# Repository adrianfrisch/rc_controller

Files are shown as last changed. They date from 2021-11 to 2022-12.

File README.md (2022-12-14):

# Universal DIY Remotecontroller

For my RC and robotics projects, I needed a better way to remote control my devices. 
So this is my attempt on building a handheld remote control, which I can use on any of 
my current and future projects.

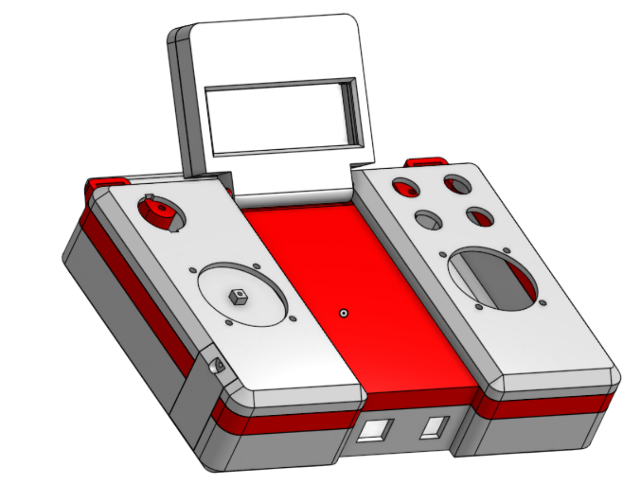
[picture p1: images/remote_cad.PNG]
CAD design screenshot

## Goals
The new controller should have two operation modes. Since I used the App "Bluetooth RC Controller" 
in the past for a project, It should have a bluetooth operation mode which operates similar and can be used 
instead of the mobile phone with app.
For other projects the transmission should be in the 2.4 GHz band to achieve a higher range.
The display should be readable also outdoors in the sun so I decided to go with a simple LCD 
module instead of a more fancy TFT.

## Features
- Bluetooth mode
- 2.4 GHz mode
- Push buttons for mode selection. After mode has been selected, can be used as switches to trigger actions
- After operation mode (BT / 2.4GHz) has been selected, a target device can be selected
- list of potential target devices will be configured in firmware
- two joystick knobs
- A display to show information
- power switch

## Benefits
- Just one remote necessary
- Reasonable price (I payed ~70€ for the parts)
- Very flexible
- Can display useful information or telemetry data on remote

## Specifications
This list contains all of the used components to put everything together
### Hardware / Bill of Materials
*Electronics*
- 1x Arduino Mega Microcontroller
- 1x HD44780 1602 LCD Module
- 1x NRF24L01 2.4GHz Transceiver
- 1x HC05 Bluetooth Transceiver
- 1x 220Ohms resistor
- 1x 10-100uF capacitor
- 1x 10kOhms linear potentiometer
- 2x 10kOhms resistor
- 1x Power Switch
- 4x Push Buttons
- 2x 4-Axis joystick potentiometer
- 1x 2s 7.4V  900mAh Lipo battery
*3D printed parts*
- 1x lower body 
- 1x upper body
- 1x left panel
- 1x right panel
- 1x handle
- 1x display case front
- 1x display case backplate
- 1x battery cover plate
- 2x display connector
*Screws, nuts etc.*
- 10x M2 Screws 6mm
- 12x 3x10mm screws
- 2x M4 Screws 12mm
- 4x M4 Washers
- 2x M4 Nuts
- hot glue
- CA glue
- heat shrink tube
## Test results
It is still work in progress. First successful data transmitted but lots of work remaining.
## Identified problems
It is still work in progress. First successful data transmitted but lots of work remaining.
## Future ideas
- The backplate of the LCD display mount needs to be glued at the moment. Add proper lid with screws.
- Calibration on power up as a "third mode selection" to allow recalib and eliminate need for 
  hardcoding in the firmware
- Save telemetry data to SD for latter analysis
- Build a corresponding universal receiver which can be used as a "plug in replacement" for a 
  standard RC-Receiver based on "16-channel PWM/Servo Shield -> NRF24L01 -> Arduino Nano"

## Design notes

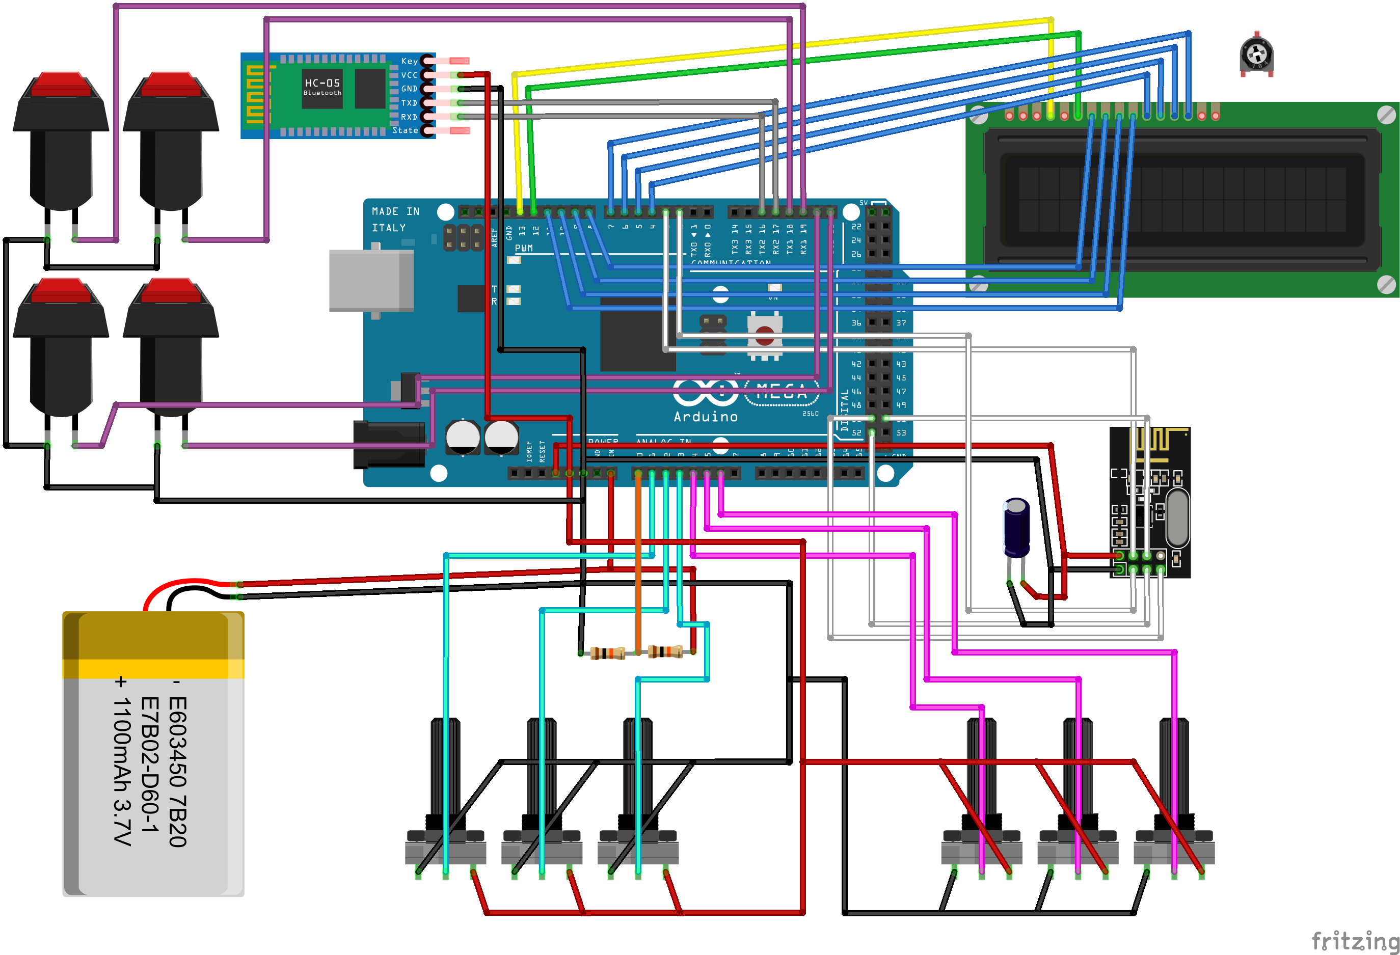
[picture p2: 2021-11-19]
fritzing/rc_controller_Steckplatine.png

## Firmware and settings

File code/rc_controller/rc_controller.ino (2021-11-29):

#include <RingBuf.h>
#include <SPI.h> 
#include <nRF24L01.h>
#include <RF24.h>
#include <LiquidCrystal.h>
// Keep in Mind: Bluetooth modules need pairing before they send / receive data.
#include <ArduinoBlue.h>

// Flag to toggle logging all data to the serial monitor
#define DEBUG false
// Pin for battery monitoring
#define BATTERY_STATUS_PIN A0
// Converting the battery reading 
#define VOLTAGE_SLOPE 0.0098484848
#define VOLTAGE_OFFSET -0.21
#define VOLTAGE_FULL 8.4
#define VOLTAGE_EMPTY 7.2

// Pins for the potis of the 2 joysticks
#define AXIS1_X_PIN A4
#define AXIS1_Y_PIN A5
#define AXIS1_Z_PIN A6
#define AXIS2_X_PIN A3
#define AXIS2_Y_PIN A2
#define AXIS2_Z_PIN A1

// Threshold for interrupt handling of button presses to avoid multiple triggers
#define BUTTON_THRESHOLD 200
// Using interrupt capable digital pins for the 4 pushbuttons
#define BUTTON_1 19
#define BUTTON_2 20
#define BUTTON_3 18
#define BUTTON_4 21

// Connectors for the NRF24L01
#define NRF_MISO 50 
#define NRF_MOSI 51
#define NRF_SCK 52 
#define NRF_CE 2
#define NRF_CSN 3

// Connectors for the LCD Display
#define LCD_RS 13
#define LCD_ENABLE 12
#define LCD_D0 8
#define LCD_D1 9
#define LCD_D2 10
#define LCD_D3 11
#define LCD_D4 4
#define LCD_D5 5
#define LCD_D6 6
#define LCD_D7 7

// Size of the ringbuffer which will be used for a running average to smooth out
// the jittering of the joystick knobs. 
#define BUFFER_SIZE 3

#define MODE_SETUP 0
#define MODE_BT 1
#define MODE_24GHZ 2

int axis1_x;
RingBuf<int,BUFFER_SIZE> x1;
int axis1_y;
RingBuf<int,BUFFER_SIZE> y1;
int axis1_z;
RingBuf<int,BUFFER_SIZE> z1;
int axis1_b;

int axis2_x;
RingBuf<int,BUFFER_SIZE> x2;
int axis2_y;
RingBuf<int,BUFFER_SIZE> y2;
int axis2_z;
RingBuf<int,BUFFER_SIZE> z2;
int axis2_b;

// Button state
byte b1 = 0;
byte b2 = 0;
byte b3 = 0;
byte b4 = 0;

// current battery status 
float batteryVoltage = 0;

// Using 8 PIN Mode since faster
LiquidCrystal lcd(LCD_RS, LCD_ENABLE, LCD_D0, LCD_D1, LCD_D2, LCD_D3, LCD_D4, LCD_D5, LCD_D6, LCD_D7);

RF24 radio(NRF_CE,NRF_CSN);
const byte address[5] = {'0','0','0','0','1'};
byte dataToSend[16];

int mode = MODE_SETUP;
int cursorPosition = 0;
int removed;
long lastButtonPressDetected;
void modeSelection() {
    lcd.setCursor(2,0);
    lcd.print("Bluetooth Mode");
    lcd.setCursor(2,1);
    lcd.print("Wifi Mode");

    lcd.setCursor(0,0);
    lcd.print(">");

    while (mode == MODE_SETUP){
      lcd.setCursor(0,0);
      lcd.print(" ");
      lcd.setCursor(0,1);
      lcd.print(" ");
      lcd.setCursor(0,cursorPosition);
      lcd.print(">");
      delay(50);
    }
    lcd.clear();
    lcd.setCursor(14,0);
    if (mode == MODE_BT){
      lcd.print("BT");
    } else {
      lcd.print("24");
    }
}
void configurePushbuttons() {
    pinMode(BUTTON_1,INPUT_PULLUP);
    pinMode(BUTTON_2,INPUT_PULLUP);
    pinMode(BUTTON_3,INPUT_PULLUP);
    pinMode(BUTTON_4,INPUT_PULLUP);
    attachInterrupt(digitalPinToInterrupt(BUTTON_1),button1Pressed,FALLING);
    attachInterrupt(digitalPinToInterrupt(BUTTON_2),button2Pressed,FALLING);
    attachInterrupt(digitalPinToInterrupt(BUTTON_3),button3Pressed,FALLING);
    attachInterrupt(digitalPinToInterrupt(BUTTON_4),button4Pressed,FALLING);
}

void setup(){
    Serial.begin(9600);
    // Bluetooth Serial on Serial2
    Serial2.begin(9600);
    configurePushbuttons();
    // Initially fill the ringbuffers
    for (int i=0 ; i<BUFFER_SIZE ;i++){
        x1.push(0); 
        y1.push(0);
        z1.push(0);
        x2.push(0);
        y2.push(0);
        z2.push(0);
    }
    lcd.begin(16, 2);
    lcd.clear();
    modeSelection();
    Serial.println(radio.begin());
    radio.begin();
    radio.setDataRate( RF24_250KBPS );
    radio.setRetries(3,5);
    radio.openWritingPipe(address);
}   

int average(RingBuf<int,BUFFER_SIZE> *buff){
    long sum = 0;
    for (int i=0 ; i<BUFFER_SIZE ; i++){        
        int val = buff->operator[](i);
        sum += val;    
    }
    return sum/BUFFER_SIZE;
}
void readAllAnalogPositions() {
    axis1_x = analogRead(AXIS1_X_PIN);
    lcd.setCursor(0, 1);
    lcd.print(map(axis1_x,0,1024,0,99));
    axis1_y = analogRead(AXIS1_Y_PIN);
    lcd.setCursor(3,1);
    lcd.print(map(axis1_y,0,1024,0,99));
    axis1_z = analogRead(AXIS1_Z_PIN);
    lcd.setCursor(6,1);
    lcd.print(map(axis1_z,0,1024,0,99));
    axis1_x = analogRead(AXIS1_X_PIN);
    lcd.setCursor(9, 1);
    lcd.print(map(axis2_x,0,1024,0,99));
    axis1_y = analogRead(AXIS1_Y_PIN);
    lcd.setCursor(12,1);
    lcd.print(map(axis2_y,0,1024,0,99));
    axis1_z = analogRead(AXIS1_Z_PIN);
    lcd.setCursor(15,1);
    lcd.print(map(axis2_z,0,1024,0,99));
    x1.pop(removed);
    y1.pop(removed);
    z1.pop(removed);
    x1.push(axis1_x);
    y1.push(axis1_y);
    z1.push(axis1_z);
    
    axis2_x = analogRead(AXIS2_X_PIN);
    axis2_y = analogRead(AXIS2_Y_PIN);
    axis2_z = analogRead(AXIS2_Z_PIN);
    x2.pop(removed);
    y2.pop(removed);
    z2.pop(removed);
    x2.push(axis2_x);
    y2.push(axis2_y);
    z2.push(axis2_z);
    batteryVoltage = analogRead(BATTERY_STATUS_PIN)*VOLTAGE_SLOPE+VOLTAGE_OFFSET;
    byte batteryPercent = byte((batteryVoltage - VOLTAGE_EMPTY)/(VOLTAGE_FULL-VOLTAGE_EMPTY));
    lcd.setCursor(0, 8);
    lcd.print(batteryPercent);
    
}
void printStatusToSerial() {
    if (DEBUG) {
      Serial.print(average(&x1));Serial.print(',');
      Serial.print(average(&y1));Serial.print(',');
      Serial.print(average(&z1));Serial.print(',');
      Serial.print(average(&x2));Serial.print(',');
      Serial.print(average(&y2));Serial.print(',');
      Serial.print(average(&z2));Serial.print(',');
      Serial.print(b1);Serial.print(',');
      Serial.print(b2);Serial.print(',');
      Serial.print(b3);Serial.print(',');
      Serial.print(b4);Serial.print(',');
      Serial.print(batteryVoltage);Serial.print('\n');      
    }
}
void send() {
    int toConvert = average(&x1);
    byte firstByte = byte(toConvert >> 8);
    byte secondByte = byte(toConvert & 0x00FF);
    bool rslt;
    dataToSend[0] = firstByte;
    dataToSend[1] = secondByte;
    toConvert = average(&y1);
    firstByte = byte(toConvert >> 8);
    secondByte = byte(toConvert & 0x00FF);
    dataToSend[2] = firstByte;
    dataToSend[3] = secondByte;
    toConvert = average(&z1);
    firstByte = byte(toConvert >> 8);
    secondByte = byte(toConvert & 0x00FF);
    dataToSend[4] = firstByte;
    dataToSend[5] = secondByte;
    toConvert = average(&x2);
    firstByte = byte(toConvert >> 8);
    secondByte = byte(toConvert & 0x00FF);
    dataToSend[6] = firstByte;
    dataToSend[7] = secondByte;
    toConvert = average(&y2);
    firstByte = byte(toConvert >> 8);
    secondByte = byte(toConvert & 0x00FF);
    dataToSend[8] = firstByte;
    dataToSend[9] = secondByte;
    toConvert = average(&z2);
    firstByte = byte(toConvert >> 8);
    secondByte = byte(toConvert & 0x00FF);
    dataToSend[10] = firstByte;
    dataToSend[11] = secondByte;
    dataToSend[12] = b1;
    dataToSend[13] = b2;
    dataToSend[14] = b3;
    dataToSend[15] = b4;
    rslt = radio.write( &dataToSend, sizeof(dataToSend) );    
}
void loop(){
    lcd.setCursor(0,0);
    lcd.print("RC");    
    readAllAnalogPositions();           
    if (mode == MODE_BT){
        char command = getCommand(axis2_x,axis1_y);
        Serial.println(command);
        Serial2.print(command);
        delay(50);
    } else if (mode == MODE_24GHZ){
        send();
        delay(50);       
    } else {
        Serial.print("DEFAULT");
        delay(50);               
    }    
    printStatusToSerial();
       
}

void button1Pressed(){
  if (millis() - lastButtonPressDetected < BUTTON_THRESHOLD){
    return;
  }
  lastButtonPressDetected = millis();
  Serial.println("B1");
  switch (mode) {
  case MODE_SETUP:
    cursorPosition = cursorPosition == 0 ? 1 : 0;
    break;
  default:
    b1 = (b1 == 0 ? 1 : 0);
    break;
  }
  delay(50);
}
void button2Pressed(){
  if (millis() - lastButtonPressDetected < BUTTON_THRESHOLD){
    return;
  }
  lastButtonPressDetected = millis();
  Serial.println("B2");
  switch (mode){
  case MODE_SETUP:
    cursorPosition = cursorPosition == 0 ? 1 : 0;
    break;
  default:
    b2 = (b2 == 0 ? 1 : 0);
    break;
  }
  delay(50);
}
void button3Pressed(){
  if (millis() - lastButtonPressDetected < BUTTON_THRESHOLD){
    return;
  }
  lastButtonPressDetected = millis();
    Serial.println("B3");
    b3 = (b3 == 0 ? 1 : 0);
    delay(50);
}
void button4Pressed(){
  if (millis() - lastButtonPressDetected < BUTTON_THRESHOLD){
    return;
  }
  lastButtonPressDetected = millis();
  Serial.println("B4");
  Serial.println(mode);
  switch (mode) {
  case MODE_SETUP:
    if (cursorPosition == 0) {
      mode = MODE_BT;
    } else {
      mode = MODE_24GHZ;
    }
    break;
  default:
    b4 = (b4 == 0 ? 1 : 0);
    break;
  }
  delay(50);
}

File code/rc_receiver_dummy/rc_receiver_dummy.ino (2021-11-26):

#include <SPI.h>
#include <nRF24L01.h>
#include <RF24.h>

#define CE_PIN   7
#define CSN_PIN 8

const byte address[5] = {'0','0','0','0','1'};

RF24 radio(CE_PIN, CSN_PIN);

byte dataReceived[16]; // this must match dataToSend in the TX
bool newData = false;

void setup() {

    Serial.begin(9600);

    Serial.println("Receiver Dummy Starting");
    radio.begin();
    radio.setDataRate( RF24_250KBPS );
    radio.openReadingPipe(1, address);
    radio.startListening();
}

void loop() {
    readData();
    printData();
}

void readData() {
    if ( radio.available() ) {
        radio.read( &dataReceived, sizeof(dataReceived) );
        newData = true;
    }
}

void printData() {
    if (newData == true) {
        Serial.print("Data received ");
        for (int i = 0; i < 11; i+= 2) {
          int val = int(dataReceived[i]<<8) + int(dataReceived[i+1]);
          Serial.print(val);
          Serial.print(',');
        }
        Serial.print(dataReceived[12]);
        Serial.print(',');
        Serial.print(dataReceived[13]);
        Serial.print(',');
        Serial.print(dataReceived[14]);
        Serial.print(',');
        Serial.print(dataReceived[15]);        
        Serial.println();        
        
        newData = false;
    }
}

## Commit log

2021-11-16 moved cad screenshot to image folder
2021-11-16 picky case
2021-11-16 fingers crossed
2021-11-16 Reading analogue input and button actions
2021-11-16 sample receiver code for testing and debugging added
2021-11-19 Added more details in BOM
2021-11-19 Wire diagramm added
    [rc_controller.fzz]
2021-11-19 Battery status PIN
2021-11-19 Updated wiring diagramm
    [rc_controller.fzz]
2021-11-29 Battery monitoring
